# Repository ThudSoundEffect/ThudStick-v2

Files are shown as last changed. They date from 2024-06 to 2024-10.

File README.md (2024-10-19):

# ThudStick v2
Fightstick with fully analog joystick functions as a gamecube controller utilizing a motherboard based on the PHOB v2.0.5, a 3D printed case, and a custom designed PCB to host the hall effect sensors to fit a Sanwa-JLF joystick based on the Sharp Analog Snap-In. 
Credit to:
- Sharp Analog Snap-In: https://github.com/ThudSoundEffect/ThudStick-v2
- PhobGCC v2.0.5

### Features
- Full analog joystick
- Digital face buttons (A,B,X,Y,Z)
- Digital C-Stick
- Digital hard shield and light shield buttons
- Powered by a custom motherboard based on the PHOB v2.0.5
# Assembly
### Parts
- x1 ThudStick v2 motherboard
- x4 12mm M3 screws
- x1 Sanwa JLF joysick (https://www.amazon.com/dp/B01CRQMWEQ?ref=ppx_yo2ov_dt_b_product_details&th=1)
- x1 Gamecube controller cord (https://www.ebay.com/itm/256017929306)
- x1 Set of 3D printed joystick parts
- x2 Hall effect sensors (https://www.digikey.com/en/products/detail/texas-instruments/DRV5053EAQLPphoG/5051704)
- x1 3D printed enclosure
- x4 50mm M5 screws
- x4 20mm M5 screws
- x4 M5 t-nuts (https://www.amazon.com/dp/B07H57TRN4?psc=1&ref=ppx_yo2ov_dt_b_product_details)
- x14 button upper and lower housing
- x14 keyswitches
- x14 keycaps
### Purchasing
- Use JLCPCB for purchasing the PCBs
- Use JLCPCB with the 8001 Transparent Resin for the 3D printed joystick parts
- Keycaps can be [3D printed](https://github.com/rana-sylvatica/circle-keycaps) or be [purchased](https://ko-fi.com/s/02dc1dde96)
### Joystick Modification
- Refer to steps 2 and 3 from https://github.com/Sharp-02/JLF-Sharp-Analog-Snap-In#step-2--restrictor-gate-and-trimming
- Take the original joystick motherboard and desolder all 4 switches
- Open up each of the swithes
- Remove the metal support on the left side of each switch
- trim the switch housing up to the point where the mechanical pieces begin on the left side (when the red piece is facing you)
- Remove the red piece
- Put the trimmed cover back on the trimmed switch
- Glue each of the switches back into its original location and solder the one metal support back into the pcb
- To properly attach the magnets place them in the slider arms so that when they are held by the linear guide they are on the same side
- Take the joystick motherboard and place the hall effect sensors in the labeled ports so that the smaller face of the sensor is pointing away from the center of the board
- Solder in the hall effect sensors and trim the excess sensor legs and solder on the bottom of the pcb
- Connect wires into each of available spots on the edge of the board
- Connect the wires to the corresponding spots on the left side of the ThudStick v2 motherboard
- Put the joystick pcb in its 3d printed holder
- Place the slider arms in the linear guide so that the magnets move in front of the hall effect sensors when the linear guide is screwed in
- Use 20mm m3 screws and bolts to affix the linear guide to the pcb
- Connect this 3d assembly back into the joystick making sure the hall effect sensor that is connected to the X data ports on the motherboard is on the bottom or top
### PCB
- Flash the v0.29 PHOB software to the motherboard
- Place the lower half of the button housing on all of the keyswitches
- Solder each keyswitch into the motherboard
### Final Assembly
- Use 4 standoffs, 20mm M5 screws, and nuts to affix the motherboard to the aluminum faceplate
- Place the aluminum faceplate on the case
- Use 4 50 mm M5 screws and 4 M5 t-nut fittings to connect the aluminum faceplate to the case
- Screw on the top housing for each of the buttons and put keycap on each
### Contact
If you'd like to purchase a controller message me on [reddit](reddit.com/u/ThudS0undEffect) or on my [Etsy shop](https://www.etsy.com/shop/thudgcc)
Message me if you have any questions or ideas for controllers I could help with. 
Discord: thudsoundeffect

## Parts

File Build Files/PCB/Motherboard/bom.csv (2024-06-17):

Designator | Footprint | Quantity | Value | LCSC Part #
C1 | CP_EIA-3528-12_Kemet-T_Pad1.50x2.35mm_HandSolder | 1 | 47u | C136751
C14, C15 | 0402 | 2 | 27p | C1557
C16, C18 | 0805 | 2 | 10u | C15850
C17, C19, C20, C22, C24, C25, C26, C27, C28, C29, C30, C31, C32, C33, C34 | 0402 | 15 | 100n | C1525
C21, C23 | 0402 | 2 | 1u | C52923
C3, C6, C7, C8 | C_0603_HandSoldering | 4 | 0.047u | C1622
D1, D5 | D_SOD-323 | 2 | CUS10S30,H3F | C146335
D2 | D_SOD-123 | 1 | M7C | C8598
F1 | 1206 | 1 | Fuse | C69680
J8 | USB_Micro-B_Amphenol_10118194_Horizontal | 1 | USB_B_Micro | C132563
Q1, Q3 | SOT-23 | 2 | Q_NMOS_GSD | C20917
Q2 | SOT-23 | 1 | Q_PMOS_GDS | C15127
R1, R2, R7, R8, R9 | 0402 | 5 | 180 | C38941
R10, R19, R24, R25 | 0402 | 4 | 316 | C159037
R11, R12 | 0603 | 2 | 100R | C22775
R13, R14, R15 | 0603 | 3 | 10k | C25804
R16, R18 | 0402 | 2 | 1k | C11702
R17 | 0603 | 1 | 100k | C25803
R20, R21 | 0402 | 2 | 27 | C25100
R26, R27, R28, R29 | 0603 | 4 | 5.6k | C114627
R30, R31 | 0603 | 2 | 1.1k | C137780
R5, R6 | 0603 | 2 | 2k | C22975
S1 | SW_TS-1187A-B-A-B | 1 | BOOTSEL
U1, U4 | SOIC-8_3.9x4.9mm_P1.27mm | 2 | MCP3202 | C56997
U12, U13 | SOT-666 | 2 | USBLC6-2P6 | C2827693
U6 | SOT-223-3_TabPin2 | 1 | AMS1117-3.3 | C6186
U7 | SOIC-8_5.23x5.23mm_P1.27mm | 1 | W25Q128JVS | C97521
U8 | RP2040-QFN-56 | 1 | RP2040 | C2040
Y1 | Crystal_SMD_3225-4Pin_3.2x2.5mm | 1 | Crystal_GND24 | C403945

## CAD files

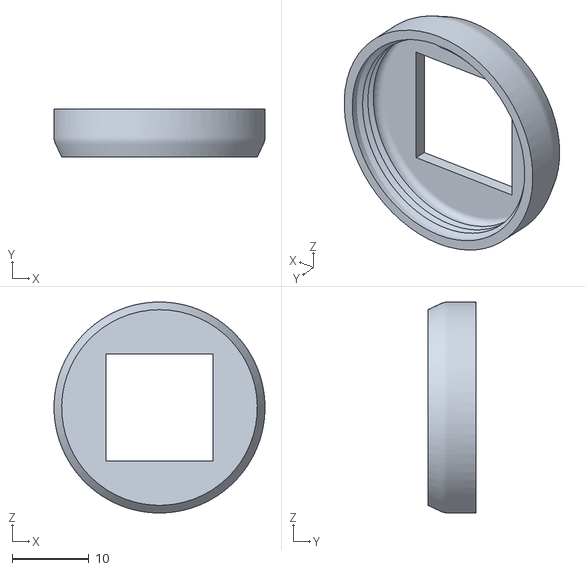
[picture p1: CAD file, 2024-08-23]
Build Files/3D Printed Parts/Button Housing/Housing_bottom.STL
27.5 x 6.30 x 27.5

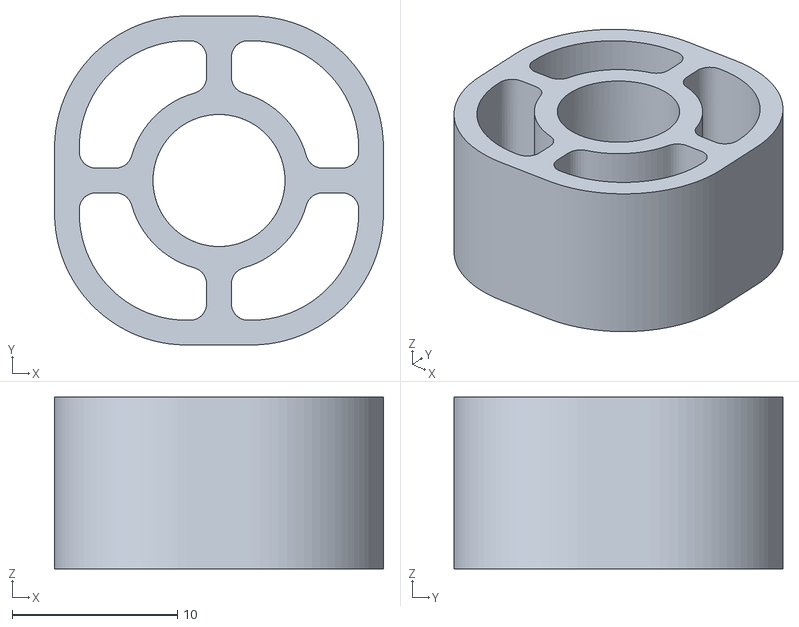
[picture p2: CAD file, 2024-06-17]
Build Files/3D Printed Parts/Standoff.stl
19.9 x 19.9 x 10.4

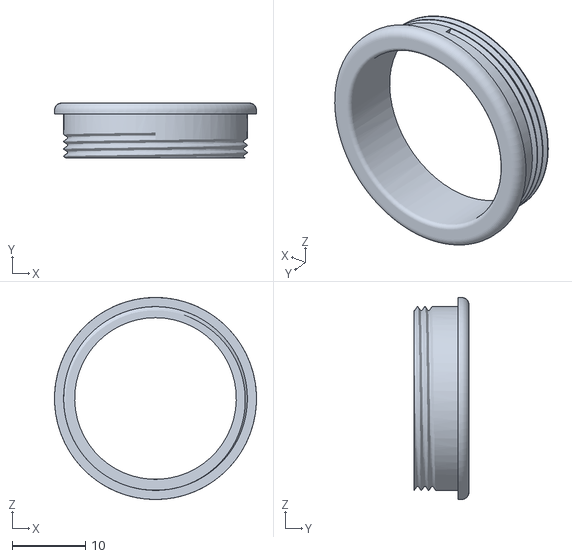
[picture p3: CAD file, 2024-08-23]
Build Files/3D Printed Parts/Button Housing/Housing_top.STL
27.5 x 7.50 x 27.5

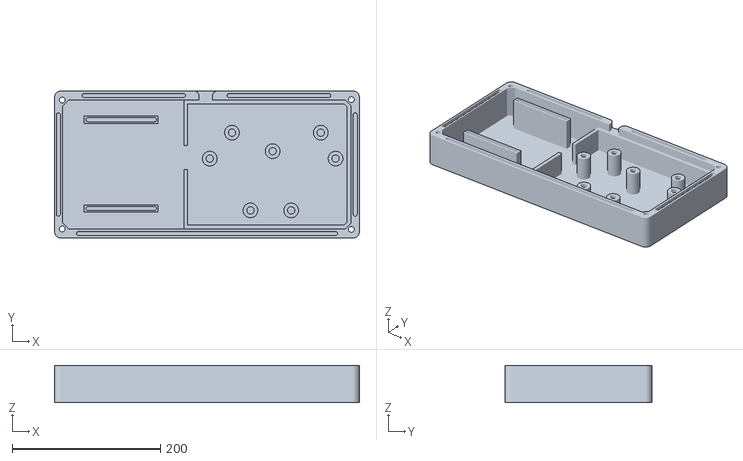
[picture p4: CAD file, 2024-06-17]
Build Files/3D Printed Parts/ThudStick v2.stl
412.1 x 199.0 x 50.0

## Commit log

2024-06-17 Create Assembly Files
2024-08-23 Rename ThudStick v2 with supports - Full.stl to ThudStick v2.stl
    [ThudStick v2.stl]
2024-08-23 Rename standoff v1.stl to Standoff.stl
    [Standoff.stl]
